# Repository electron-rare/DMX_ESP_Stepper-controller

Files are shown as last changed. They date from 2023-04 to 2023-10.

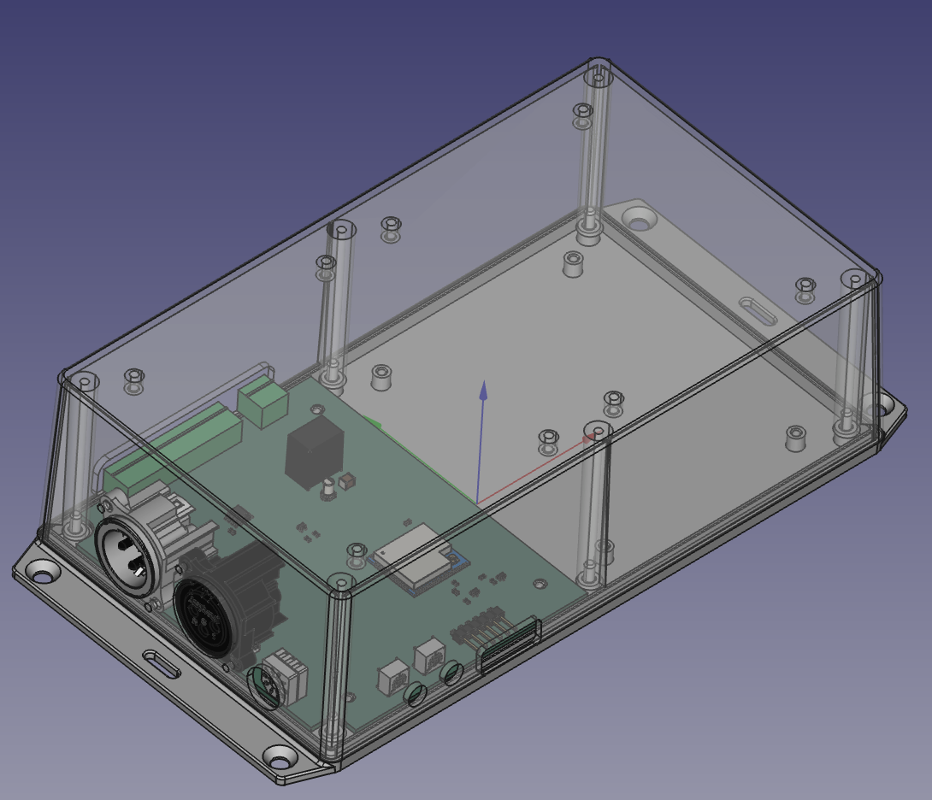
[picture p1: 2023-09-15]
3D view.png

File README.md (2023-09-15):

# DMX_ESP_Stepper-controller

controle de moteur pas à pas selon commande DMX

Clément SAILLANT pour Hémisphère - 2023

c.saillant@gmail.com

0625334420

3D view

Un canal DMX est utilisé pour la commande de la position du moteur

Un autre canal DMX est utilisé pour la commande de la vitesse du moteur

Une fonction affine est utilisée pour convertir la valeur DMX en position ou vitesse

La position et la vitesse sont stockées dans des variables globales

Une fonction est utilisée pour la sécurité si un obstacle est détecté par la perte de pas du moteur

moteur : 34HS59-6004D-E1000

Angle de pas: 1.8 deg

Résolution de l'encodeur: 1000PPR(4000CPR)

https://www.omc-stepperonline.com/download/34HS59-6004D-E1000_Torque_Curve.pdf
https://www.omc-stepperonline.com/download/34HS59-6004D-E1000.pdf

Controleur CL86T V4.0

https://www.omc-stepperonline.com/index.php?route=product/product/get_file&file=389/CL86T%20(V4.0).pdf

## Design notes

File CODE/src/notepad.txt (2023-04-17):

https://github.com/arttupii/CLSMB Closed loop step motor controller

https://www.switchdoc.com/2018/04/esp32-tutorial-debouncing-a-button-press-using-interrupts/
avec vtask pour plus d'efficacité

voir pour mieur gérer le homming avec les fonctions explicité dans la lib felxystepper

rajouter plus de délai à la lecture dmx pour mieux éviter les problème de chanement de valeurs trop rapide

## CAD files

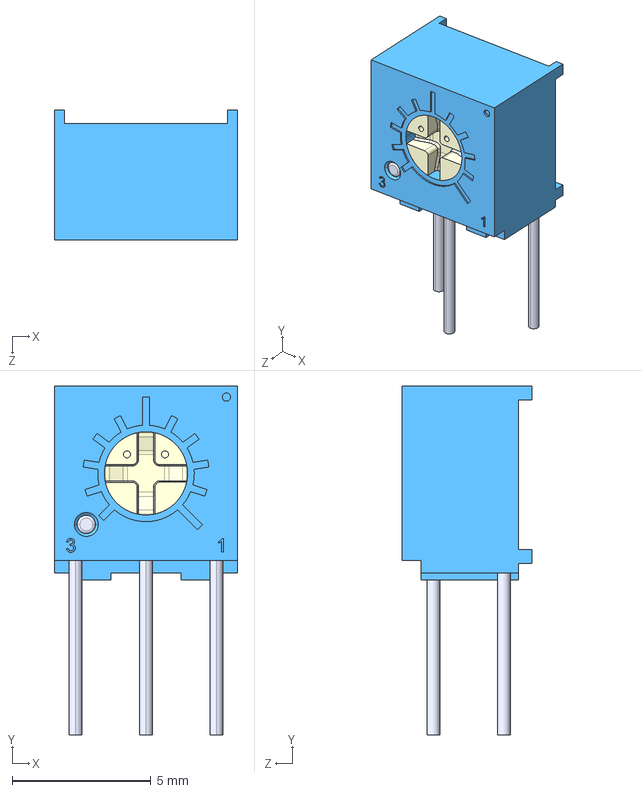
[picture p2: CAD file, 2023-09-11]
PCB/3D/3362W-1-104LF.STEP
6.60 x 12.6 x 4.70 mm

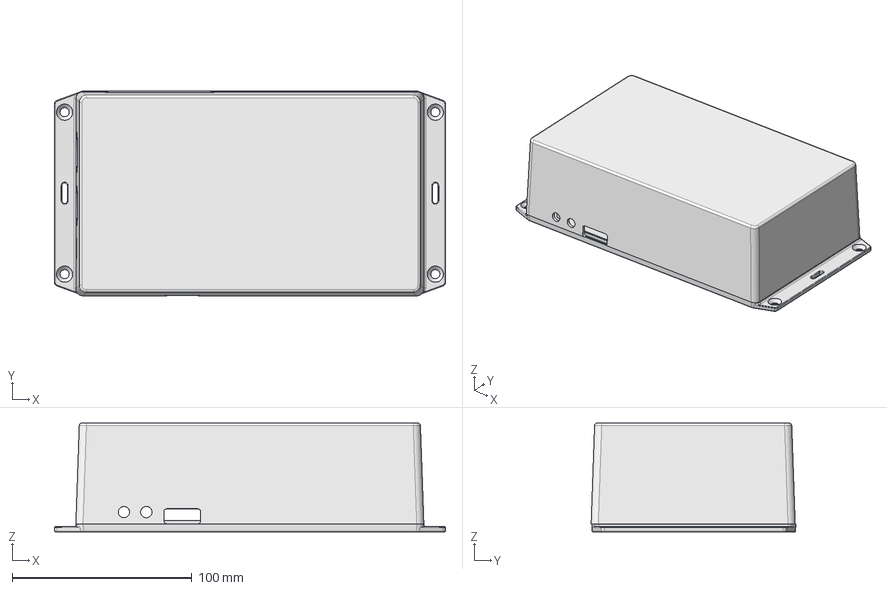
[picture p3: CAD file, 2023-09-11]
PCB/Casing 5.FCStd
217.3 x 113.8 x 60.5 mm
1591XXEFLLID
SC510 (screw #4X 1_2'' FH)
SC510 (screw #4X 1_2'' FH)001
SC510 (screw #4X 1_2'' FH)002
SC510 (screw #4X 1_2'' FH)003
SC510 (screw #4X 1_2'' FH)004
SC510 (screw #4X 1_2'' FH)005
Corps

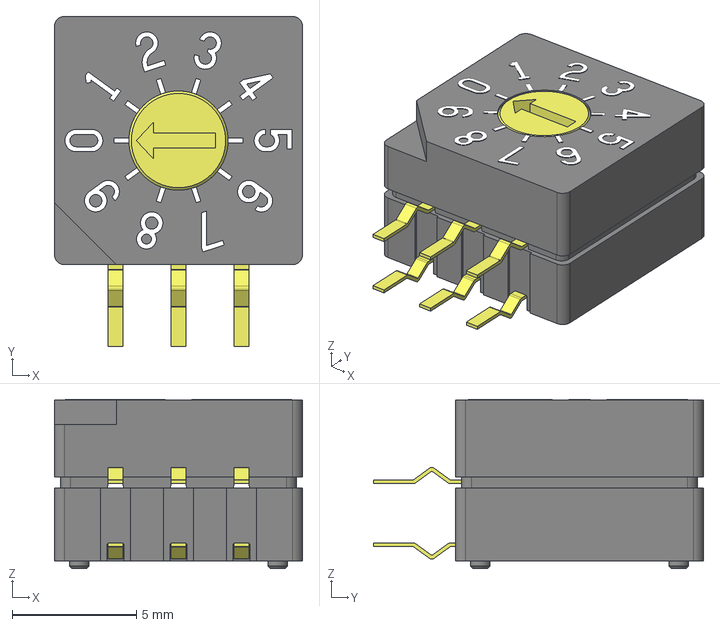
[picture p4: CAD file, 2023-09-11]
PCB/3D/SD-2011.stp
10.0 x 13.3 x 6.82 mm
SD-1_di
SD-2011_b

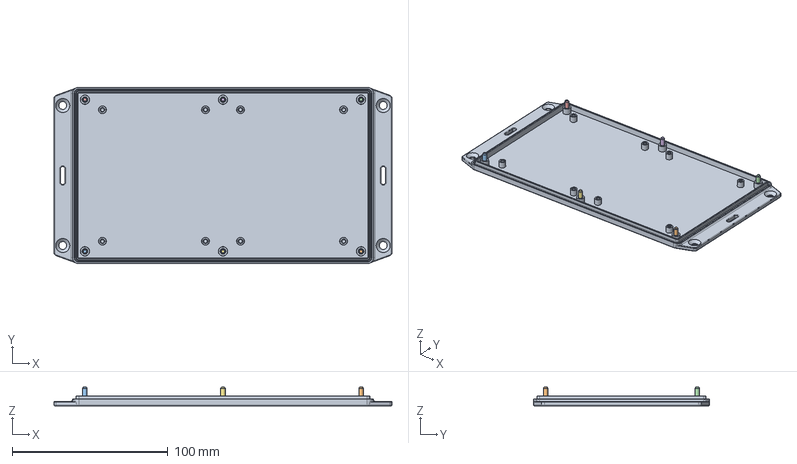
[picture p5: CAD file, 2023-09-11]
PCB/Casing 3.FCStd
217.3 x 113.4 x 12.1 mm
1591XXEFLLID
SC510 (screw #4X 1_2'' FH)
SC510 (screw #4X 1_2'' FH)001
SC510 (screw #4X 1_2'' FH)002
SC510 (screw #4X 1_2'' FH)003
SC510 (screw #4X 1_2'' FH)004
SC510 (screw #4X 1_2'' FH)005

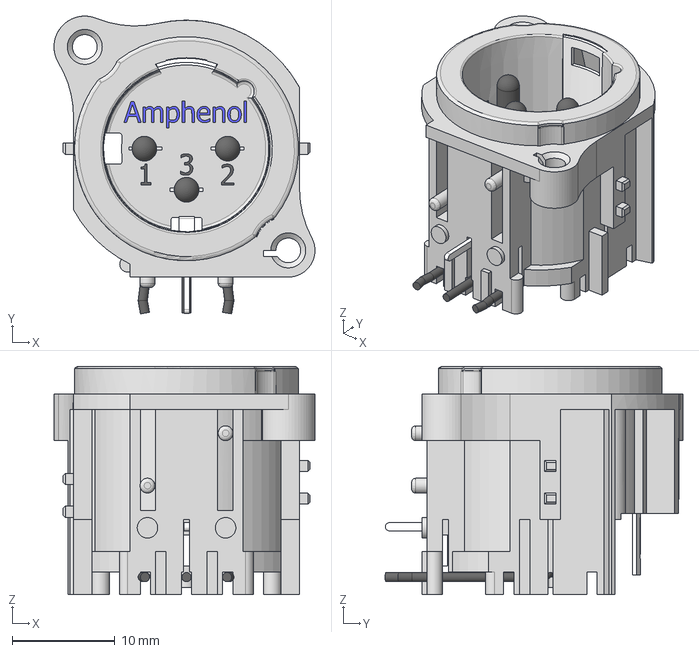
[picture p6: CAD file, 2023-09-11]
PCB/3D/ac3mah-au-pre-c3d.STP
25.4 x 29.0 x 22.2 mm

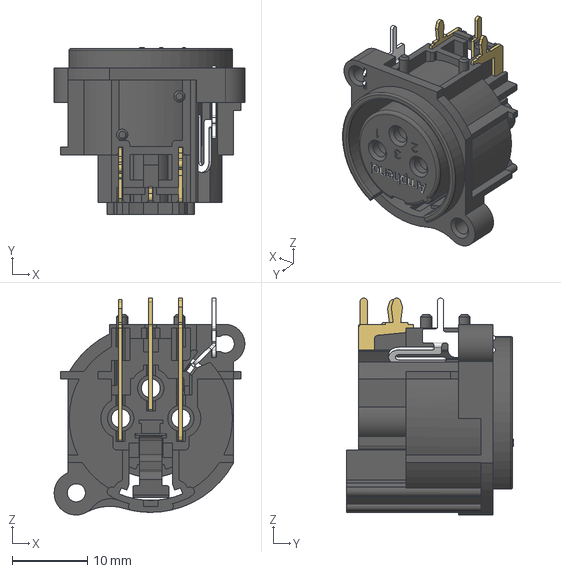
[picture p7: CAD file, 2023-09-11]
PCB/3D/ac3fahl2-au-pre-c3d.STP
25.3 x 22.2 x 28.8 mm

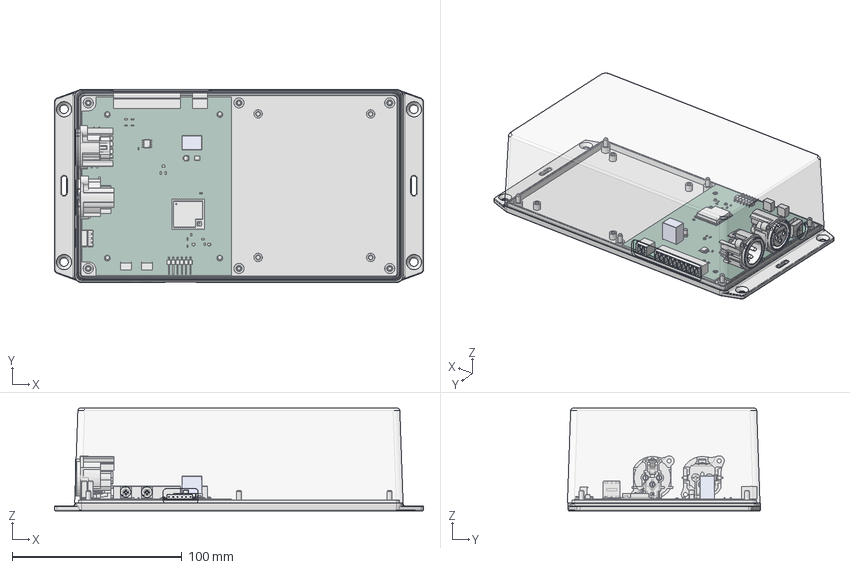
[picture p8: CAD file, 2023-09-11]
PCB/Casing 7.FCStd
217.3 x 113.8 x 60.5 mm
1591XXEFLLID
SC510 (screw #4X 1_2'' FH)
SC510 (screw #4X 1_2'' FH)001
SC510 (screw #4X 1_2'' FH)002
SC510 (screw #4X 1_2'' FH)003
SC510 (screw #4X 1_2'' FH)004
SC510 (screw #4X 1_2'' FH)005
Corps
PCB PCB001

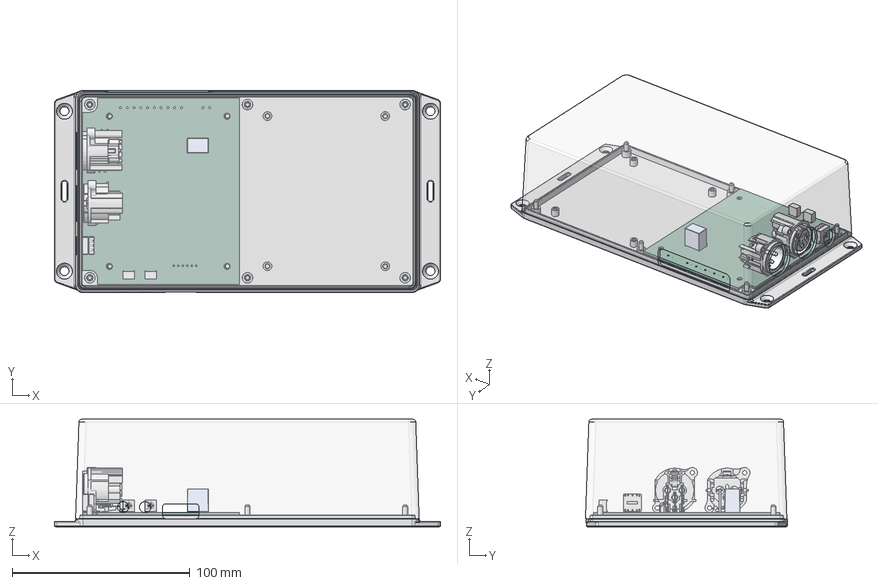
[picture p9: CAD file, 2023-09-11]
PCB/Casing 6.FCStd
217.3 x 113.8 x 60.5 mm
1591XXEFLLID
SC510 (screw #4X 1_2'' FH)
SC510 (screw #4X 1_2'' FH)001
SC510 (screw #4X 1_2'' FH)002
SC510 (screw #4X 1_2'' FH)003
SC510 (screw #4X 1_2'' FH)004
SC510 (screw #4X 1_2'' FH)005
Corps
PCB PCB

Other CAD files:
PCB/Casing.step
PCB/Casing 4.FCStd
PCB/Casing.FCStd

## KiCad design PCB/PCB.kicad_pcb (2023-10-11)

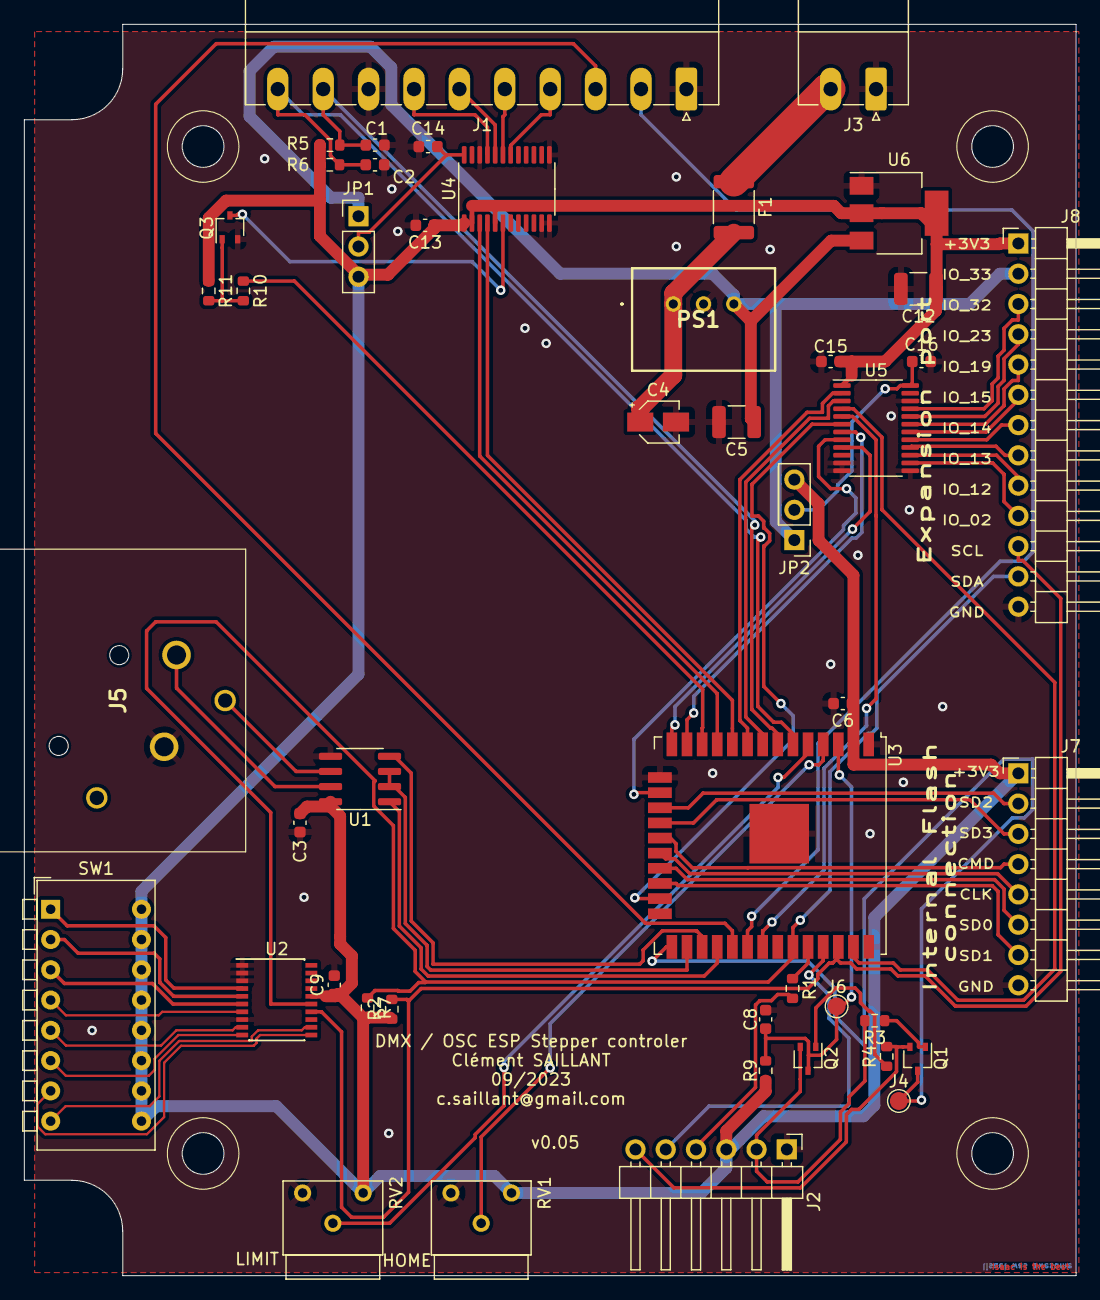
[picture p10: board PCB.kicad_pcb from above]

Board: 2 copper layers, 88.2 x 105.0 mm, 47 parts (0 on the bottom side), 68 nets.

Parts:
C1, C2: 100nF; C_0603_1608Metric
C3, C6, C9, C13, C14, C15, C16: 0.1uF; C_0603_1608Metric
C4: 10uF/100V; CP_Elec_3x5.3
C5, C12: 10uF/100V; C_1210_3225Metric
C8: 1uF; C_0603_1608Metric
F1: 0.5A/100V; Fuse_1812_4532Metric
J1: Conn_01x10_Socket; PhoenixContact_MC_1,5_10-G-3.81_1x10_P3.81mm_Horizontal
J2: Conn_01x06; PinHeader_1x06_P2.54mm_Horizontal
J3: Screw_Terminal_01x02; PhoenixContact_MC_1,5_2-G-3.81_1x02_P3.81mm_Horizontal
J4, J6: TEST_1P; TestPoint_Pad_D1.5mm
J5: DMX-IN; AC3FAHL2-AU-PRE
J7: Conn_01x08; PinHeader_1x08_P2.54mm_Horizontal
J8: Conn_01x13; PinHeader_1x13_P2.54mm_Horizontal
JP1, JP2: Jumper_3_Open; PinHeader_1x03_P2.54mm_Vertical
PS1: TSR 0.6-4850WI; TSR0648120WI
Q1, Q2, Q3: BC847W; SOT-323_SC-70
R1, R10: 1k; R_0603_1608Metric
R2, R7: 4.7k; R_0603_1608Metric
R3, R4, R5, R6, R9, R11: 10k; R_0603_1608Metric
RV1, RV2: R_Potentiometer; Potentiometer_Bourns_3339W_Horizontal
SW1: SW_DIP_x08; SW_DIP_SPSTx08_Piano_CTS_Series194-8MSTN_W7.62mm_P2.54mm
U1: SP3485CN; SOIC-8_3.9x4.9mm_P1.27mm
U2: PCF8574; SSOP-20_4.4x6.5mm_P0.65mm
U3: ESP32-WROOM; ESP32-WROOM-32U
U4, U5: 74LVX3245TTR; TSSOP-24_4.4x7.8mm_P0.65mm
U6: AMS1117-3.3; SOT-223-3_TabPin2

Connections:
+3V3: C3.1, C6.1, C9.1, C12.1, C13.1, C15.1, J2.3, J7.1, J8.1, JP1.3 (B), JP2.3 (B), R2.1, R5.2, R6.2, R7.2, R9.2, R11.1, RV1.1, RV2.1, SW1.9, SW1.10, SW1.11, SW1.12, SW1.13, SW1.14, SW1.15, SW1.16, U1.8 (VCC), U2.16 (VDD), U3.2 (VCC), U4.1 (VCCA), U4.2 (DIR), U4.5 (A3), U5.1 (VCCA), U6.2 (VO)
+5V: C5.1, J8.2, JP1.1 (A), JP2.1 (A), PS1.3 (+VOUT), U6.3 (VI)
/CLK: J7.5, U3.20 (CLK/IO6)
/CMD: J7.4, U3.19 (CMD/IO11)
/DIR+: U3.10 (IO25), U4.4 (A2)
/DMX/XLR_DMX_2: J5.2, U1.7 (B)
/DMX/XLR_DMX_3: J5.3, U1.6 (A)
/DMX_DE: U1.2 (~RE), U1.3 (DE), U3.26 (IO4)
/DMX_DI: U1.4 (DI), U3.27 (IO16)
/DMX_RO: U1.1 (RO), U3.28 (IO17)
/EA+: J1.3, U3.29 (IO5)
/EB+: J1.2, U3.30 (IO18)
/ENA: R10.1, U3.12 (IO27)
/ENA-: Q3.3 (C), U4.6 (A4)
/END_POT: RV2.2, U3.5 (SENSOR_VN)
/END_SWITCH: C1.1, J1.9, R5.1, U3.7 (IO35)
/ESP32_BOOT: J4.1, Q1.3 (C), U3.25 (IO0)
/ESP32_EN: C8.1, J6.1, Q2.3 (C), R9.1, U3.3 (EN)
/ESP32_RXI: R1.1, U3.34 (RXD0)
/ESP32_TXO: J2.5, U3.35 (TXD0)
/IO12: U3.14 (IO12), U5.9 (A7)
/IO13: U3.16 (IO13), U5.8 (A6)
/IO14: U3.13 (IO14), U5.7 (A5)
/IO15: U3.23 (IO15), U5.6 (A4)
/IO19: U3.31 (IO19), U5.5 (A3)
/IO23: U3.37 (IO23), U5.4 (A2)
/IO32_One-wire: U3.8 (IO32), U5.3 (A1)
/IO33: U3.9 (IO33), U5.2 (DIR)
/PROG_DTR: J2.6, Q1.2 (E), R4.2
/PROG_RTS: J2.2, Q2.2 (E), R3.2
/PUL+: U3.11 (IO26), U4.3 (A1)
/SCL: J8.11, R2.2, U2.14 (SCL), U3.36 (IO22)
/SD0: J7.6, U3.21 (SD0/IO7)
/SD1: J7.7, U3.22 (SD1/IO8)
/SD2: J7.2, U3.17 (SD2/IO9)
/SD3: J7.3, U3.18 (SD3/IO10)
/SDA: J8.12, R7.1, U2.15 (SDA), U3.33 (IO21)
/START_POT: RV1.2, U3.4 (SENSOR_VP)
/START_SWITCH: C2.1, J1.10, R6.1, U3.6 (IO34)
/Shifter level1/B1: J8.3, U5.21 (B1)
/Shifter level1/B2: J8.4, U5.20 (B2)
/Shifter level1/B3: J8.5, U5.19 (B3)
/Shifter level1/B4: J8.6, U5.18 (B4)
/Shifter level1/B5: J8.7, U5.17 (B5)
/Shifter level1/B6: J8.8, U5.16 (B6)
/Shifter level1/B7: J8.9, U5.15 (B7)
/Shifter level1/B8: J8.10, U5.14 (B8)
/Shifter level stepper/B1: J1.7, U4.21 (B1)
/Shifter level stepper/B2: J1.6, U4.20 (B2)
/Shifter level stepper/B3: J1.5, U4.19 (B3)
/Shifter level stepper/B4: J1.4, U4.18 (B4)
/VDD_EXP: C16.1, JP2.2 (C), U5.24 (VCCB)
/VDD_STEPPER: C14.1, JP1.2 (C), U4.24 (VCCB)
GND: C1.2, C2.2, C3.2, C4.2, C5.2, C6.2, C8.2, C9.2, C12.2, C13.2, C14.2, C15.2, C16.2, J1.1, J1.8, J2.1, J3.1, J5.1, J7.8, J8.13, PS1.2 (GND), Q3.2 (E), RV1.3, RV2.3, U1.5 (GND), U2.1 (A0), U2.2 (A1), U2.3 (A2), U2.8 (VSS), U3.1 (GND), U3.15 (GND), U3.38 (GND), U3.39 (GND_PAD), U4.11 (GND), U4.12 (GND), U4.13 (GND), U4.22 (*G), U5.11 (GND), U5.12 (GND), U5.13 (GND), U5.22 (*G), U6.1 (GND)
unnamed: J2.4, R1.2
unnamed: F1.1, J3.2
unnamed: C4.1, F1.2, PS1.1 (+VIN)
unnamed: Q1.1 (B), R3.1
unnamed: Q2.1 (B), R4.1
unnamed: Q3.1 (B), R10.2, R11.2
unnamed: SW1.1, U2.4 (P0)
unnamed: SW1.2, U2.5 (P1)
unnamed: SW1.3, U2.6 (P2)
unnamed: SW1.4, U2.7 (P3)
unnamed: SW1.5, U2.9 (P4)
unnamed: SW1.6, U2.10 (P5)
unnamed: SW1.7, U2.11 (P6)
unnamed: SW1.8, U2.12 (P7)

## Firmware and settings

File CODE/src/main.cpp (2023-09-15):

/*
controle de position et vitesse pour moteur pas à pas selon commande DMX

code par Clément SAILLANT pour Hémisphère - 2023
c.saillant@gmail.com
0625334420

Un canal DMX est utilisé pour la commande de la position du moteur
Un autre canal DMX est utilisé pour la commande de la vitesse du moteur
Une fonction affine est utilisée pour convertir la valeur DMX en position ou vitesse
La position et la vitesse sont stockées dans des variables globales
Une fonction est utilisée pour la sécurité si un obstacle est détecté par la perte de pas du moteur

moteur : 34HS59-6004D-E1000
Angle de pas: 1.8 deg
Résolution de l'encodeur: 1000PPR(4000CPR)
https://www.omc-stepperonline.com/download/34HS59-6004D-E1000_Torque_Curve.pdf
https://www.omc-stepperonline.com/download/34HS59-6004D-E1000.pdf

Controleur CL86T V4.0
https://www.omc-stepperonline.com/index.php?route=product/product/get_file&file=389/CL86T%20(V4.0).pdf
*/

#include "PIN_mapping.h"    // fichier contenant les variables globales et le mapping des pins
bool emergencyStop = false; // variable pour stocker l'état de l'arrêt d'urgence

#include <Arduino.h>
#include <esp_dmx.h>
#include <ESP_FlexyStepper.h> // librairie pour le controle des moteurs pas à pas
#include <ESP32Encoder.h>     // librairie pour le controle des encodeurs

ESP_FlexyStepper stepper; // création de l'ojet motor
ESP32Encoder encoder;     // création de l'objet encoder

#include "limit.h"    // fichier contenant les fonctions de limites
#include "dmx_data.h" // fichier contenant les fonctions dmx
#include "moving.h"   // fichier contenant les fonctions de mouvement
#include "security.h" // fichier contenant les fonctions de sécurité type emergency stop


void setup()
{
  // delay(1000);
  Serial.begin(115200);
  Serial.println("started");

  dmx_set_pin(dmx_num, tx_pin, rx_pin, rts_pin);
dmx_driver_install(dmx_num, &config, DMX_INTR_FLAGS_DEFAULT);

  // configuration encoder pour suivre la position du moteur et la perte de pas
  encoder.attachHalfQuad(EB_plus, EA_plus);
  encoder.setCount(0);

  // configuration ENABLE motor
  pinMode(MOTOR_ENABLE_PIN, OUTPUT);

  // configuration BCD Coder
  pinMode(q1, INPUT); // thumbwheel '1'
  pinMode(q2, INPUT); // thumbwheel '2'
  pinMode(q4, INPUT); // thumbwheel '4'
  pinMode(q8, INPUT); // thumbwheel '8'

  /*
    // attach an interrupt to the IO pin of the ermegency stop switch and specify the handler function
    pinMode(EMERGENCY_STOP_PIN, INPUT_PULLUP);
    attachInterrupt(digitalPinToInterrupt(EMERGENCY_STOP_PIN), emergencySwitchHandler, RISING);
  */

  // lecture des potentiomètres pour définir les offset de pas a ajouter aux positions home et limit
  limit_steps = map((analogRead(limit_set_pot)), 4095, 0, min_offset, max_offset);
  home_steps = map((analogRead(home_set_pot)), 4095, 0, min_offset, max_offset);

  // attach an interrupt to the IO pin of the home switch and specify the handler function
  attachInterrupt(digitalPinToInterrupt(HOME_SWITCH_PIN), homeSwitchHandler, CHANGE);
  stepper.registerHomeReachedCallback(homeReachedCallback);

  // attach an interrupt to the IO pin of the limit switch and specify the handler function
  attachInterrupt(digitalPinToInterrupt(LIMIT_SWITCH_PIN), limitSwitchHandler, CHANGE);
  stepper.registerLimitReachedCallback(limitReachedCallback);

  // connect and configure the stepper motor to its IO pins
  stepper.connectToPins(MOTOR_STEP_PIN, MOTOR_DIRECTION_PIN);
  // set the speed and acceleration rates for the stepper motor
  stepper.setSpeedInStepsPerSecond(SPEED_IN_STEPS_PER_SECOND);
  stepper.setAccelerationInStepsPerSecondPerSecond(ACCELERATION_IN_STEPS_PER_SECOND);
  stepper.setDecelerationInStepsPerSecondPerSecond(DECELERATION_IN_STEPS_PER_SECOND);
  stepper.setStepsPerRevolution(STEP_PER_REV);
  stepper.registerTargetPositionReachedCallback(targetPositionReachedCallback);

  // start the stepper instance as a service in the "background" as a separate task
  stepper.startAsService(1); // core 1 sinon bug avec le dmx et déplacement aléatoire du moteur

  init_range(); // set home and limit position of the motor

  DMX_start_channel = readSwitch(); // lecture de la position du codeurs BCD pour définir le canal DMX de départ
  // DMX_start_channel = 2;            // pour test avec adresse fixe
  pos_channel = DMX_start_channel;
  speed_channel = DMX_start_channel + 1;

  Serial.println("----------------------------------------");
  Serial.printf("number of tasks is %i\n", uxTaskGetNumberOfTasks());
  Serial.printf("home position is %i\n", min_steps);
  Serial.printf("limit position is %i\n", max_steps);
  Serial.printf("Limit setting is %i\n", limit_steps);
  Serial.printf("Home setting is %i\n", home_steps);
  Serial.printf("DMX start channel is %i\n", DMX_start_channel);
  Serial.printf("DMX position channel is %i\n", pos_channel);
  Serial.printf("DMX speed channel is %i\n", speed_channel);
  Serial.println("----------------------------------------");
}

void loop()
{
  receiveDMX(); // reception des données DMX

  // mise à jour de la vitesse du moteur si la valeur DMX a changée
  if (dataChanged[speed_array] == true)
  {
    dataChanged[speed_array] = false;
    speed_map(); // fonction pour convertir la valeur DMX en vitesse/acceleration/deceleration
  }

  // mise à jour de la position du moteur si la valeur DMX a changée
  // if (dataChanged[pos_array] == true && emergencyStop == false && digitalRead(MOTOR_ENABLE_PIN) == LOW)
  if (dataChanged[pos_array] == true)
  {
    // stepper.setTargetPositionToStop();
    dataChanged[pos_array] = false;
    pos_in_step = map(DMX_data[pos_array], 255, 0, min_steps, max_steps);
    // pos_map(); // fonction pour convertir la valeur DMX en position
    stepper.setTargetPositionInSteps(pos_in_step);
    DMX_data_old[pos_array] = DMX_data[pos_array];
    last_dmx_change_pos = millis();
    Serial.printf("dmx pos to step => %ld\n", pos_in_step);
  }
  // gestion de la position du moteur si la valeur DMX n'a pas changée mais que le moteur n'est pas à la position demandée
  if (millis() - last_dmx_change_pos > 1000)
  {
    int codeur_pos = map(encoder.getCount(), min_count, max_count, min_steps, max_steps);
    if (pos_in_step <= min_steps && ConfirmedHomeSwitchState != switch_active && stepper.getDirectionOfMotion() == 0)
    {
      Serial.println("!!!!!!!!!!!!! home not reached");
      Serial.printf("codeur pos => %i\n", codeur_pos);
      // stepper.setTargetPositionInSteps(min_steps - codeur_pos); // home_steps
      int step_add = nb_microstep * 2;
      stepper.setTargetPositionRelativeInSteps(-step_add);
      delay(100);
    }
    else if (pos_in_step >= max_steps && ConfirmedLimitSwitchState != switch_active && stepper.getDirectionOfMotion() == 0)
    {
      Serial.println("!!!!!!!!!!!!! limit not reached");
      Serial.printf("codeur pos => %i\n", codeur_pos);
      // stepper.setTargetPositionInSteps(max_steps + (max_steps - codeur_pos)); // limit_steps
      int step_add = nb_microstep * 2;
      stepper.setTargetPositionRelativeInSteps(step_add);
      delay(100);
    }
    else if (abs(codeur_pos - pos_in_step) > 100 && stepper.getDirectionOfMotion() == 0)
    {
      Serial.println("!!!!!!!!!!!!! Not in position");
      Serial.printf("codeur pos => %i\n", codeur_pos);
      Serial.printf("pos in step => %i\n", pos_in_step);
      stepper.setTargetPositionInSteps(pos_in_step);
    }
  }
  // motor_follower(emergency_stop_loss_step); // fonction pour suivre la position du moteur et la perte de pas
  emergency_check(); // fonction pour la sécurité si un obstacle est détecté par la perte de pas du moteur
  limit_check();     // fonction pour la sécurité si un obstacle est détecté par le bouton poussoir
}

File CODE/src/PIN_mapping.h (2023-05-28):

/// ********************** PIN ASSIGNEMENTS **********************
// DMX
const int tx_pin = 16; // define the IO pin the DMX TX pin is connected to
const int rx_pin = 17; // define the IO pin the DMX RX pin is connected to
const int rts_pin = 4; // define the IO pin the DMX RTS pin is connected to

// capteur BCD pour adressage DMX
#define q1 21 // define the IO pin for the thumbwheel '1' is connected to
#define q2 19 // define the IO pin for the thumbwheel '2' is connected to
#define q4 18 // define the IO pin for the thumbwheel '4' is connected to
#define q8 5 // define the IO pin for the thumbwheel '8' is connected to

// driver moteur
const int MOTOR_ENABLE_PIN = 27; // define the IO pin the motor enable pin is connected to
const int MOTOR_STEP_PIN = 26; // define the IO pin the motor step pin is connected to
const int MOTOR_DIRECTION_PIN = 25; // define the IO pin the motor direction pin is connected to
#ifndef dev_mode
const int EMERGENCY_STOP_PIN = 13; // define the IO pin the emergency stop switch is connected to
#endif
const int HOME_SWITCH_PIN = 35; // define the IO pin where the home switches are connected to (switches in series in normally closed setup against ground)
const int LIMIT_SWITCH_PIN = 34; // define the IO pin where the limit switches are connected to (switches in series in normally closed setup against ground)

//  encoder moteur pas à pas
#define EB_plus 22 // define the IO pin for the encoder B is connected to
#define EA_plus 23  // define the IO pin for the encoder A is connected to

// potentiomètre pour le réglage des fins de course
#define home_set_pot 36 // define the IO pin for the home set potentiometer is connected to
#define limit_set_pot 39 // define the IO pin for the limit set potentiometer is connected to
#define divider_pot 1 // define the divider potentiometer value

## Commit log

2023-09-11 update PCB
    [3362W-1-104LF.STEP, Casing 3.FCStd, Casing 4.FCStd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]
2023-10-11 add expansion port and level shifter in progress
    [Level shifter.kicad_sch, PCB.kicad_pcb, PCB.kicad_sch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]

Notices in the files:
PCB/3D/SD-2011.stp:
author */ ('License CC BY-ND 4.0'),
